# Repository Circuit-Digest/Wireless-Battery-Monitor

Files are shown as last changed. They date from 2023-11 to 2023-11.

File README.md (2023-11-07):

# Wireless-Battery-Monitor
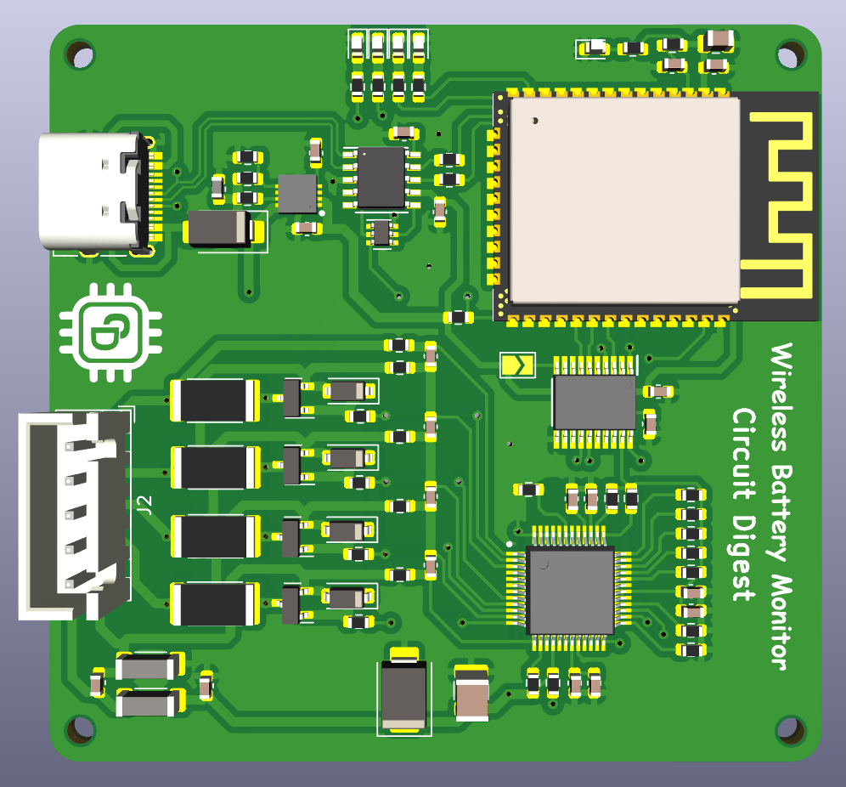
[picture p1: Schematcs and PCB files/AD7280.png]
image_tooltip

<br>

Batteries are everywhere and can be found in many of the day-to-day life equipment. Most of them are powered by Li ion or LIfepo4 batteries nowadays. Even though they need much less maintenance when compared to traditional Lead acid batteries, it is essential to regularly monitor them to avoid damage or even accidents. That’s where BMS comes into play. They not only provide safety but also help extend battery life. But the problem with most common BMSs is that, if we want to manually check the battery health, we will have to physically access it. There are BMS’s that offer wireless monitoring functionality, but the issue is that they are pretty expensive. That’s why we have decided to design and build a DIY wireless battery monitoring system, which can be used with the existing BMS.
For this project we have chosen the AD7280 Lithium-Ion Battery Monitoring chip from Analog Devices, and for wireless connectivity we have chosen our favourite ESP32. The AD7280 is capable of monitoring up to 6S battery configuration. Here we have configured it to monitor 4S battery configuration since that’s the most commonly used battery system. The AD7280 offers a 12bit ADC with a conversion time of 1 us per channel. It also features cell balancing function, which can be controlled manually. The ESP32 is used for communication and to host a Async webserver which can be used to monitor the cell voltages and charge levels.

<br>
[Note: As this projects are very simple we are only providing the code, schemaitic, and a few essential images if you want to get the images or code explanations do check out the Circuit Digest website.
<br>
<br>

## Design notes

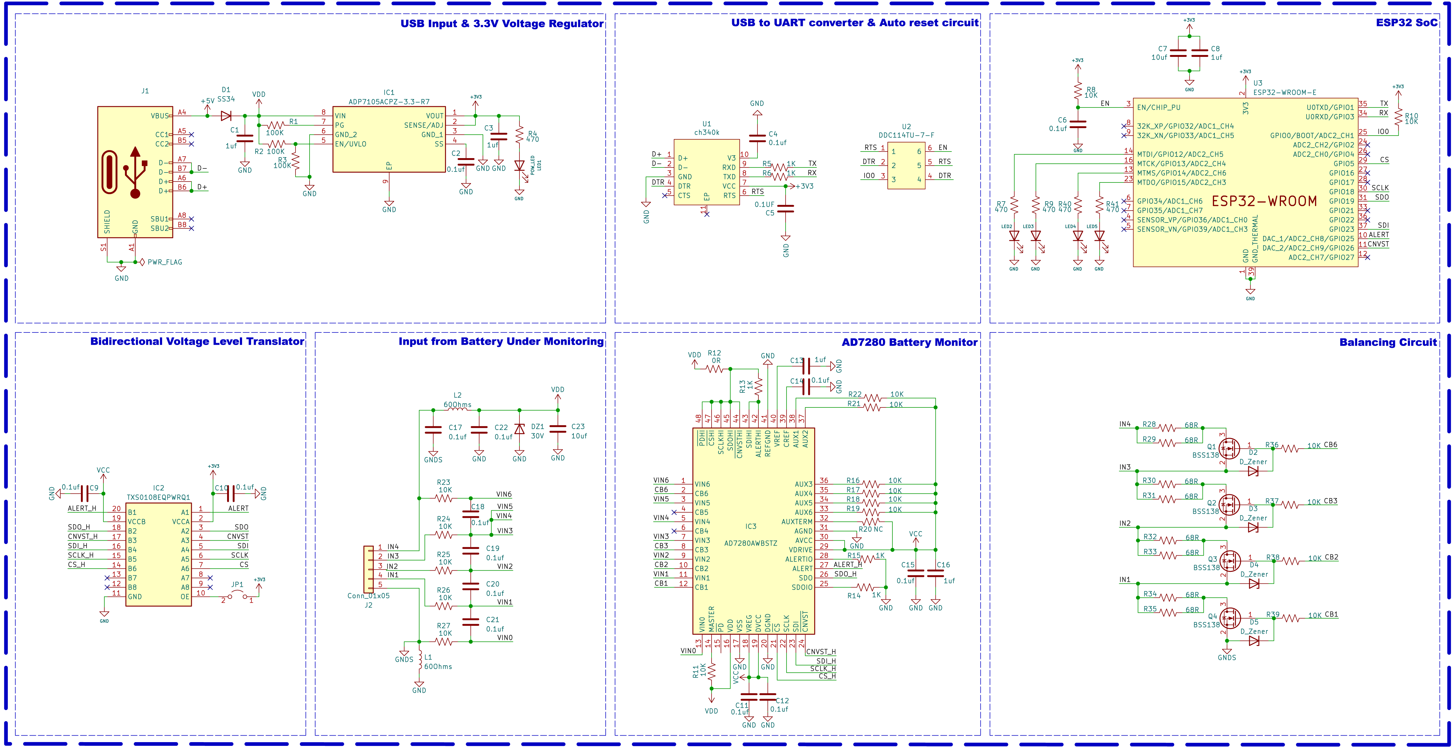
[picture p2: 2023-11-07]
Schematcs and PCB files/AD7280 sch.png

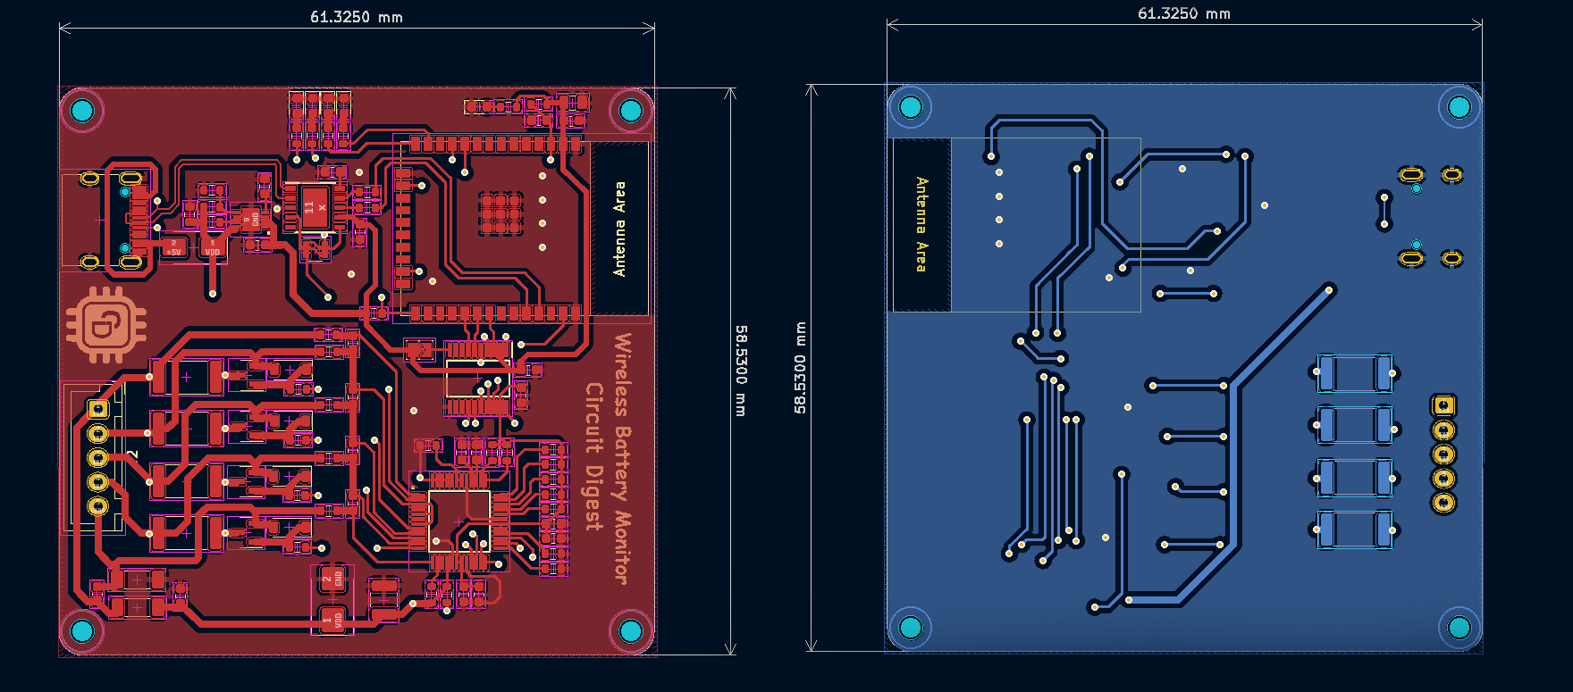
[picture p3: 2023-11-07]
Schematcs and PCB files/AD7280 PCB.png

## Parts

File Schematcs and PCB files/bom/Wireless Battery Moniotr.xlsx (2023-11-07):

Reference(s) | Value | Footprint | Manufacturer_Part_Number | Manufacturer_Name | Digikey Part Number | Digikey Link | Qty
C2, C4, C5, C6, C9, C10, C11, C12, C14, C15, C17, C18, C19, C20, C21, C22 | 0.1uf | C0603 | CL10B104KB8NNWC | Samsung Electro-Mechanics | 1276-1935-1-ND | https://www.digikey.in/en/products/detail/samsung-electro-mechanics/CL10B104KB8NNWC/3887593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 | 16
C1,C3, C8, C13, C16 | 1uf | C0603 | CL10A105KO8NNNC | Samsung Electro-Mechanics | 1276-1034-1-ND | https://www.digikey.in/en/products/detail/samsung-electro-mechanics/CL10A105KO8NNNC/3886692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 | 5
C7 | 10uf | C0805 | GRM21BR61H106KE43L | Murata Electronics | 490-18663-2-ND | https://www.digikey.in/en/products/detail/murata-electronics/GRM21BR61H106KE43L/10326316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 | 1
C23 | 10uf | C1210 | CL32B106KBJNNNE | Samsung Electro-Mechanics | 1276-3387-2-ND | https://www.digikey.in/en/products/detail/samsung-electro-mechanics/CL32B106KBJNNNE/3889045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 | 1
D1 | SS34 | SMA | SS34 | MDD | 3372-SS34TR-ND | https://www.digikey.in/en/products/detail/nextgen-components/SS34/15911595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 | 1
D2, D3, D4, D5 | D_Zener | SOD-123 | MMSZ15T1G | onsemi | MMSZ15T1GOSCT-ND | https://www.digikey.in/en/products/detail/onsemi/MMSZ15T1G/1749036 | 4
DZ1 | 30V | SMB | SMBJ30A-E3/5B | Vishay General Semiconductor | SMBJ30A-E3/5B-ND | https://www.digikey.in/en/products/detail/vishay-general-semiconductor-diodes-division/SMBJ30A-E3-5B/2147811 | 1
IC1 | ADP7105ACPZ-3.3-R7 | SON50 | ADP7105ACPZ-3.3-R7 | Analog Devices | 505-ADP7105ACPZ-3.3-R7CT-ND | https://www.digikey.in/en/products/detail/analog-devices-inc/ADP7105ACPZ-3-3-R7/10659634 | 2
IC2 | TXS0108EQPWRQ1 | SOP65 | TXS0108EQPWRQ1 | Texas Instruments | 296-42401-1-ND | https://www.digikey.in/en/products/detail/texas-instruments/TXS0108EQPWRQ1/5324256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 | 2
IC3 | AD7280AWBSTZ | QFP50 | AD7280AWBSTZ | Analog Devices | AD7280AWBSTZ-ND | https://www.digikey.in/en/products/detail/analog-devices-inc/AD7280AWBSTZ/2700188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 | 2
J1 | USB_C_Receptacle_USB2.0 | USB_C | USB4105-GF-A | GCT | 2073-USB4105-GF-ACT-ND | https://www.digikey.in/en/products/detail/gct/USB4105-GF-A/11198441 | 1
J2 | Conn_01x05 | JST_XH_B5B-XH-A_1x05 | B5B-XH-A(LF)(SN) | JST Sales America Inc. | 455-2270-ND | https://www.digikey.in/en/products/detail/jst-sales-america-inc/B5B-XH-A-LF-SN/1530483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 | 1
L1, L2 | 60Ohms | L1806 | BLM41PG600SN1L | Murata | 490-1058-2-ND | https://www.digikey.in/en/products/detail/murata-electronics/BLM41PG600SN1L/584267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 | 2
LED1 | RED LED | LED_0603 | 0603RBD0700S01 | BNDLIGHT | 3372-0603RBD0700S01TR-ND | https://www.digikey.in/en/products/detail/nextgen-components/0603RBD0700S01/14318421 | 1
LED2, LED3 | Blue LED | LED_0603 | 0603BBD0680S01 | BNDLIGHT | 3372-0603BBD0680S01TR-ND | https://www.digikey.in/en/products/detail/nextgen-components/0603BBD0680S01/14318406 | 4
Q1, Q2, Q3, Q4 | BSS138 | SOT-23 | BSS138-13-F | Diodes Incorporated | BSS138-13-F-ND | https://www.digikey.in/en/products/detail/diodes-incorporated/BSS138-13-F/9765697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 | 4
R1, R2, R3 | 100K | R0603 | CR0603JB100KS1 | Aillen | 3372-CR0603JB100KS1TR-ND | https://www.digikey.in/en/products/detail/nextgen-components/CR0603JB100KS1/14632365 | 3
R4, R7, R9 | 470R | R0603 | WR06X471 JTL | Walsin Technology Corporation | 1292-WR06X471JTLCT-ND | https://www.digikey.in/en/products/detail/walsin-technology-corporation/WR06X471-JTL/13240608 | 5
R5, R6, R13, R14, R15 | 1K | R0603 | RNCP0603FTD1K00 | Stackpole Electronics Inc | RNCP0603FTD1K00CT-ND | https://www.digikey.in/en/products/detail/stackpole-electronics-inc/RNCP0603FTD1K00/2240106 | 5
R8, R10, R11, R16, R17, R18, R19, R21, R22, R23, R24, R25, R26, R27, R36, R37, R38, R39 | 10K | R0603 | RNCP0603FTD10K0 | Stackpole Electronics Inc | RNCP0603FTD10K0CT-ND | https://www.digikey.in/en/products/detail/stackpole-electronics-inc/RNCP0603FTD10K0/2240139 | 18
R28, R29, R30, R31, R32, R33, R34, R35 | 68R | R2512 | RMCF2512JT68R0 | Stackpole Electronics Inc | 738-RMCF2512JT68R0CT-ND | https://www.digikey.in/en/products/detail/stackpole-electronics-inc/RMCF2512JT68R0/1756939 | 8
U1 | ch340k | ESSOP-10 |  |  |  |  | 1
U2 | DDC114TU-7-F | SOT-363 | DDC114TU-7-F | Diodes Incorporated | DDC114TU-FDICT-ND | https://www.digikey.in/en/products/detail/diodes-incorporated/DDC114TU-7-F/814919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 | 1
U3 | ESP32-WROOM-E | ESP32-WROOM-32E | ESP32-WROOM-32E-N16 | Espressif Systems | 1965-ESP32-WROOM-32E-N16CT-ND | https://www.digikey.in/en/products/detail/espressif-systems/ESP32-WROOM-32E-N16/11613144 | 1
U4 | ADUM3165 | ADUM3165BRSZ | ADUM3165BRSZ | Analog Devices Inc. | 505-ADUM3165BRSZ-ND | https://www.digikey.in/en/products/detail/analog-devices-inc/ADUM3165BRSZ/16580732 | 2

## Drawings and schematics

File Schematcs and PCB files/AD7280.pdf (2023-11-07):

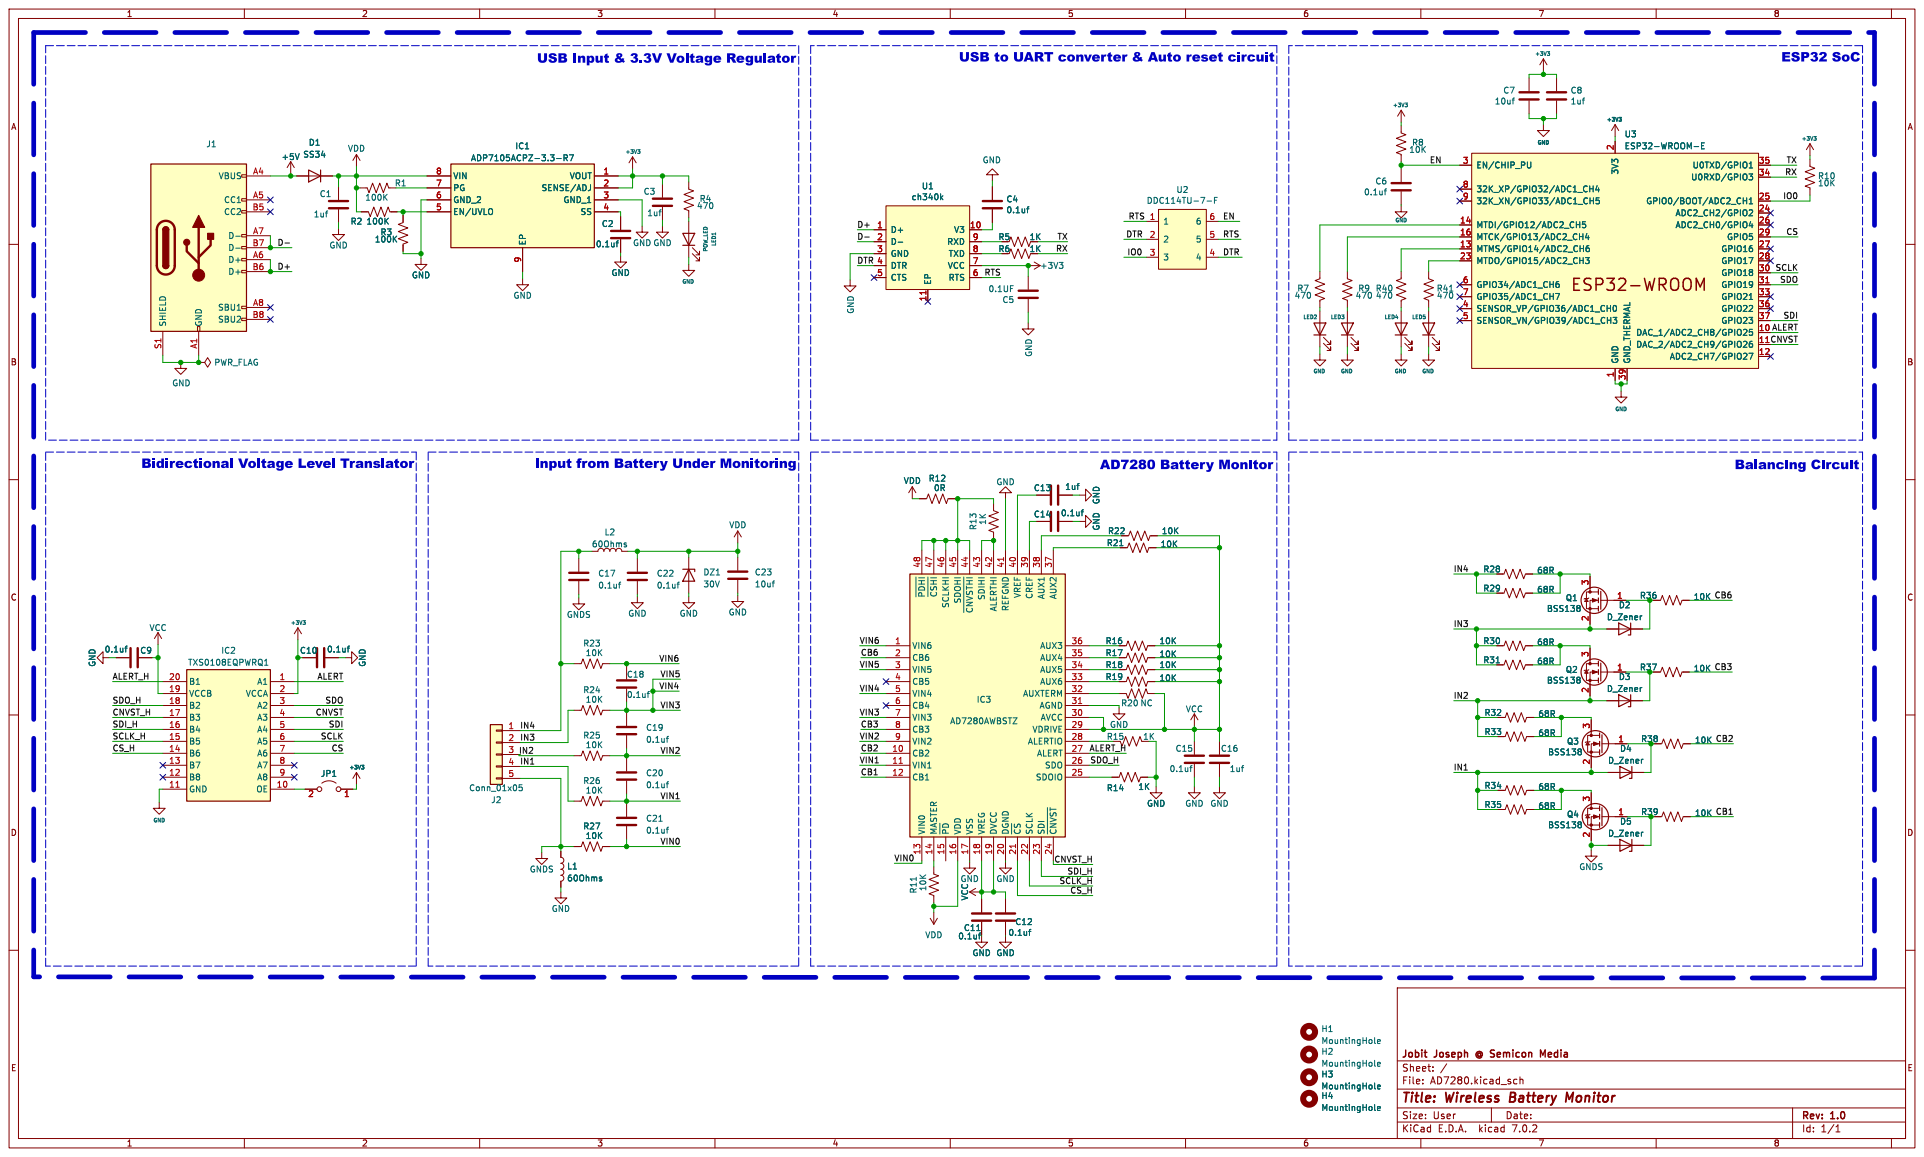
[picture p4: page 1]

USB Input & 3.3V Voltage Regulator

USB to UART converter & Auto reset circuit

Bidirectional Voltage Level Translator

H4 MountingHole H2 MountingHole H3 MountingHole H1 MountingHole

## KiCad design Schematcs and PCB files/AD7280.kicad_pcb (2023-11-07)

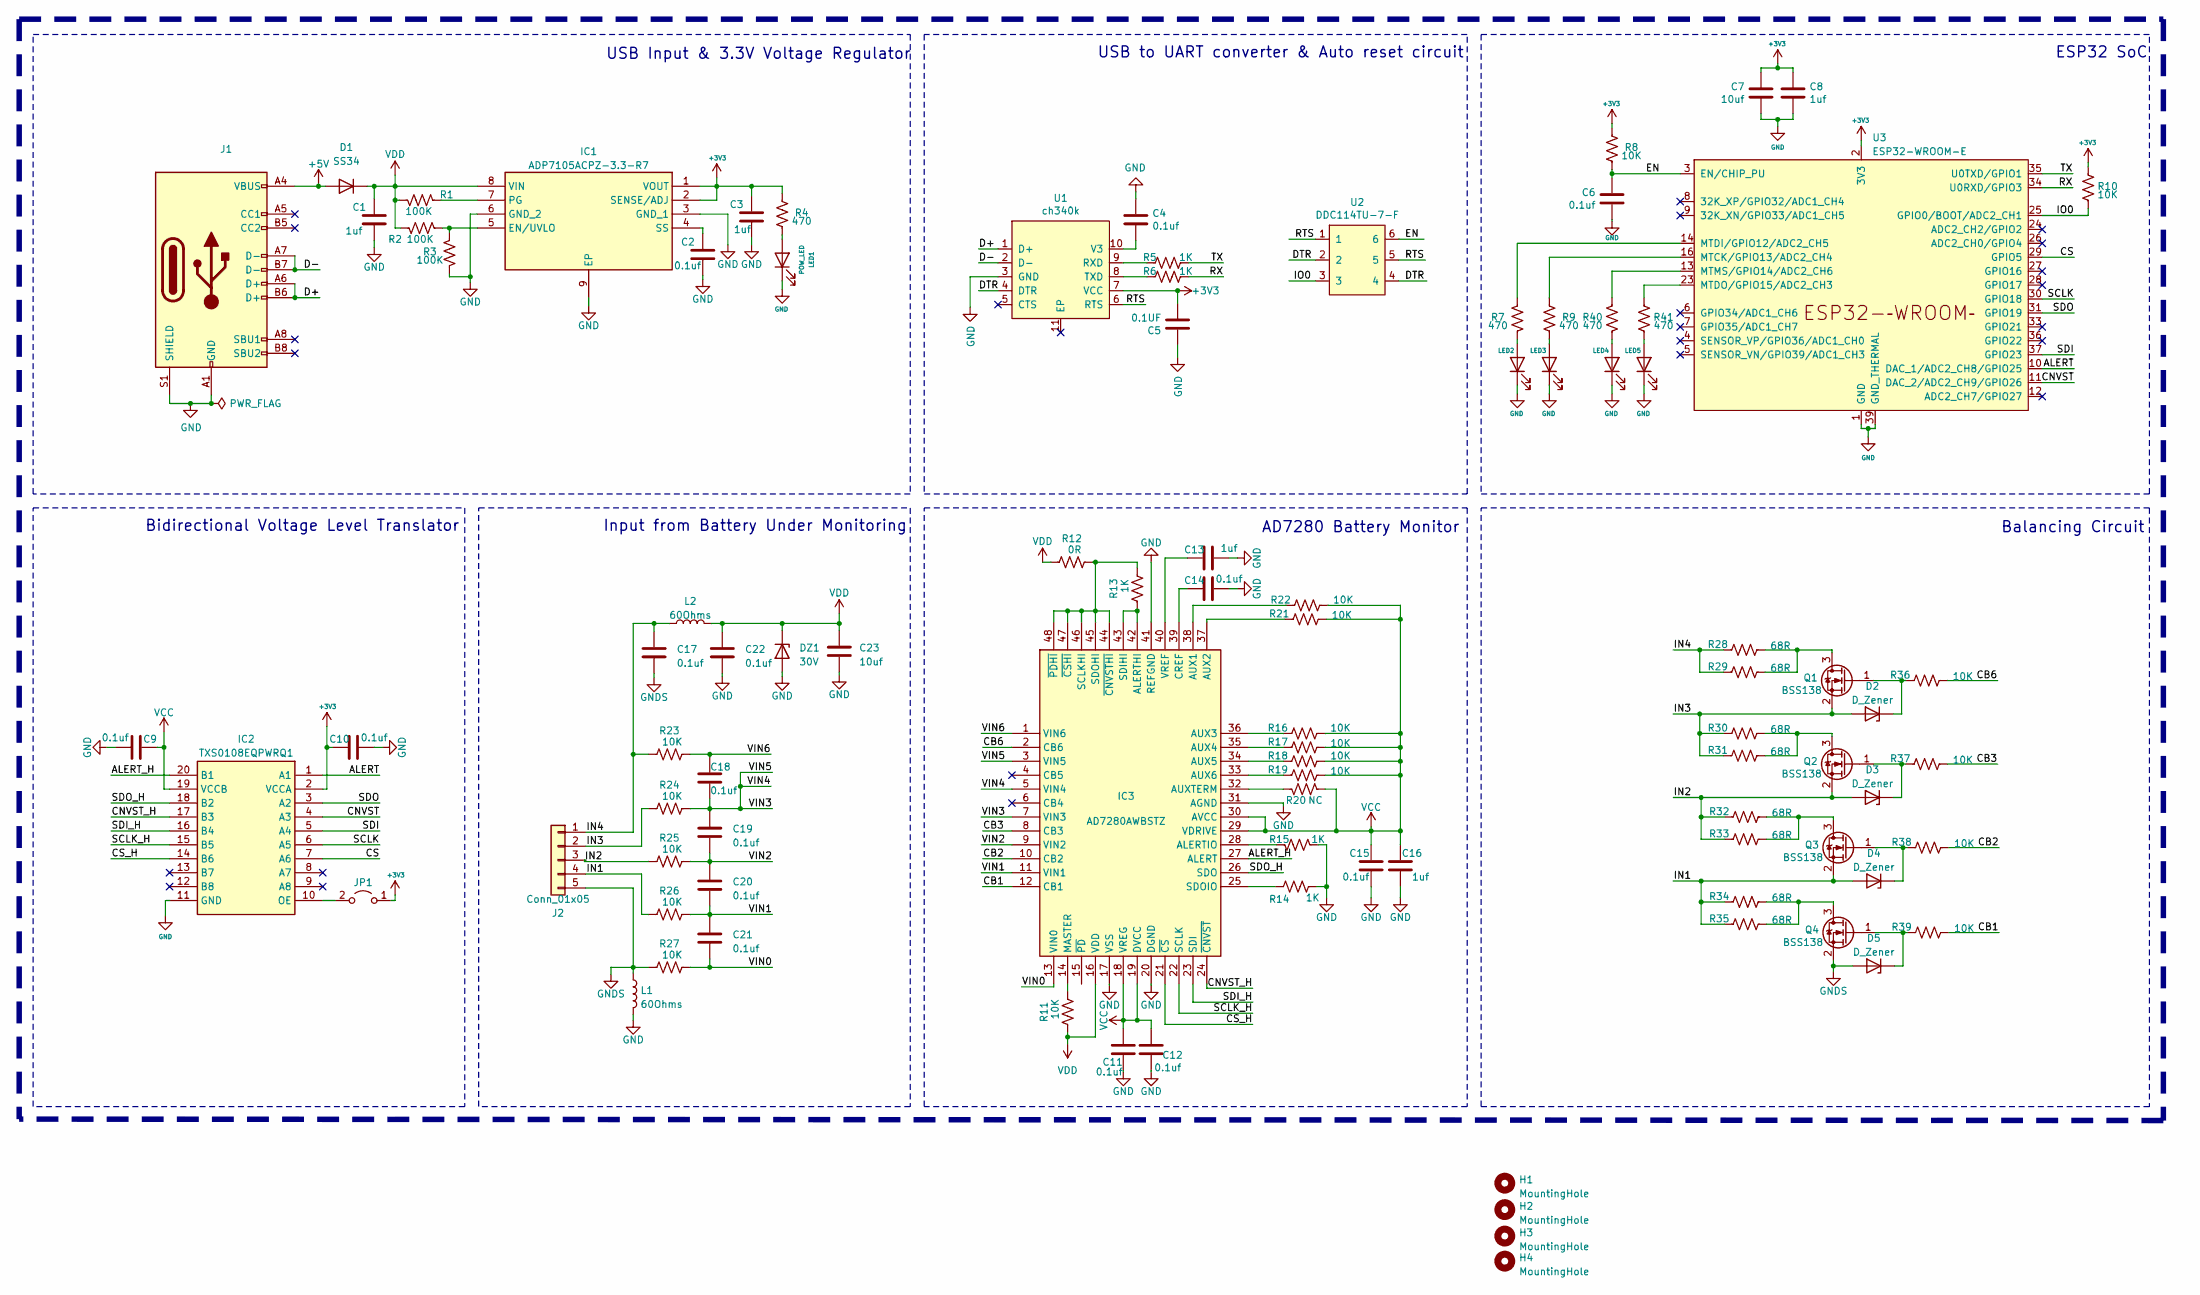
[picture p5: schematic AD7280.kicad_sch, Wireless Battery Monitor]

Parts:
C1: 1uf; L_0603_1608Metric
C2, C4, C6, C9, C10, C11, C12, C14, C15, C17, C18, C19, C20, C21, C22: 0.1uf; C_0603_1608Metric
C3, C8, C13, C16: 1uf; C_0603_1608Metric
C5: 0.1UF; C_0603_1608Metric
C7: 10uf; C_0805_2012Metric
C23: 10uf; C_1210_3225Metric
D1: SS34; D_SMA
D2, D3, D4, D5: D_Zener; D_SOD-123
DZ1: 30V; D_SMB
H1, H2, H3, H4: MountingHole; MountingHole_2.1mm
IC1: ADP7105ACPZ-3.3-R7; SON50P300X300X80-9N-D; Mouser Part Number 584-P7105ACPZ-3.3-R
IC2: TXS0108EQPWRQ1; SOP65P640X120-20N; Mouser Part Number 595-TXS0108EQPWRQ1
IC3: AD7280AWBSTZ; QFP50P900X900X160-48N; Mouser Part Number 584-AD7280AWBSTZ
J1: USB_C_Receptacle_USB2.0; USB_C_Receptacle_HRO_TYPE-C-31-M-12
J2: Conn_01x05; JST_XH_B5B-XH-A_1x05_P2.50mm_Vertical
JP1: Jumper_2_Open; SolderJumper-2_P1.3mm_Open_TrianglePad1.0x1.5mm
L1, L2: 60Ohms; L_1806_4516Metric; MFG Part number BLM41PG600SN1L
LED1, LED2, LED3, LED4, LED5: POW_LED; LED_0603_1608Metric
Q1, Q2, Q3, Q4: BSS138; SOT-23
R1, R2, R3: 100K; R_0603_1608Metric
R4, R7, R9, R40, R41: 470; R_0603_1608Metric
R5, R6, R13, R14, R15: 1K; R_0603_1608Metric
R8, R10, R11, R16, R17, R18, R19, R21, R22, R23, R24, R25, R26, R27, R36, R37, R38, R39: 10K; R_0603_1608Metric
R12: 0R; R_0603_1608Metric
R20: NC; R_0603_1608Metric
R28, R29, R30, R31, R32, R33, R34, R35: 68R; R_2512_6332Metric
U1: ch340k; ESSOP-10_3.9x4.9mm_P1.00mm
U2: DDC114TU-7-F; SOT-363_SC-70-6
U3: ESP32-WROOM-E; ESP32-WROOM-32E

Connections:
+3V3: C3.1, C5.2, C7.1, C8.1, C10.1, IC1.1 (VOUT), IC1.2 (SENSE/ADJ), IC2.2 (VCCA), JP1.1 (A), R4.2, R8.2, R10.2, U1.7 (VCC), U3.2 (3V3)
+5V: D1.2 (A), J1.A4 (VBUS), J1.A9 (VBUS), J1.B4 (VBUS), J1.B9 (VBUS)
/ALERT: IC2.1 (A1), U3.10 (DAC_1/ADC2_CH8/GPIO25)
/ALERT_H: IC2.20 (B1), IC3.27 (ALERT)
/CB1: IC3.12 (CB1), R39.2
/CB2: IC3.10 (CB2), R38.2
/CB3: IC3.8 (CB3), R37.2
/CB6: IC3.2 (CB6), R36.2
/CNVST: IC2.4 (A3), U3.11 (DAC_2/ADC2_CH9/GPIO26)
/CNVST_H: IC2.17 (B3), IC3.24 (~CNVST)
/CS: IC2.7 (A6), U3.29 (GPIO5)
/CS_H: IC2.14 (B6), IC3.21 (~CS)
/D+: J1.A6 (D+), J1.B6 (D+), U1.1 (D+)
/D-: J1.A7 (D-), J1.B7 (D-), U1.2 (D-)
/DTR: U1.4 (DTR), U2.2, U2.4
/EN: C6.1, R8.1, U2.6, U3.3 (EN/CHIP_PU)
/IN1: D4.2 (A), J2.4, Q3.2 (S), R26.1, R34.1, R35.1
/IN2: D3.2 (A), J2.3, Q2.2 (S), R25.1, R32.1, R33.1
/IN3: D2.2 (A), J2.2, Q1.2 (S), R24.1, R30.1, R31.1
/IN4: C17.1, J2.1, L2.1, R23.1, R28.1, R29.1
/IO0: R10.1, U2.3, U3.25 (GPIO0/BOOT/ADC2_CH1)
/RTS: U1.6 (RTS), U2.1, U2.5
/RX: R6.2, U3.34 (U0RXD/GPIO3)
/SCLK: IC2.6 (A5), U3.30 (GPIO18)
/SCLK_H: IC2.15 (B5), IC3.22 (SCLK)
/SDI: IC2.5 (A4), U3.37 (GPIO23)
/SDI_H: IC2.16 (B4), IC3.23 (SDI)
/SDO: IC2.3 (A2), U3.31 (GPIO19)
/SDO_H: IC2.18 (B2), IC3.26 (SDO)
/TX: R5.2, U3.35 (U0TXD/GPIO1)
/VIN0: C21.2, IC3.13 (VIN0), R27.2
/VIN1: C20.2, C21.1, IC3.11 (VIN1), R26.2
/VIN2: C19.2, C20.1, IC3.9 (VIN2), R25.2
/VIN3: C18.2, C19.1, IC3.3 (VIN5), IC3.5 (VIN4), IC3.7 (VIN3), R24.2
/VIN6: C18.1, IC3.1 (VIN6), R23.2
GND: C1.2, C2.2, C3.2, C4.1, C5.1, C6.2, C7.2, C8.2, C9.2, C10.2, C11.2, C12.2, C13.2, C14.2, C15.2, C16.2, C22.2, C23.2, DZ1.2 (A), IC1.3 (GND_1), IC1.6 (GND_2), IC1.9 (EP), IC2.11 (GND), IC3.17 (VSS), IC3.20 (DGND), IC3.31 (AGND), IC3.41 (REFGND), J1.A1 (GND), J1.A12 (GND), J1.B1 (GND), J1.B12 (GND), J1.S1 (SHIELD), L1.2, LED1.1 (K), LED2.1 (K), LED3.1 (K), LED4.1 (K), LED5.1 (K), R3.1, R14.1, R15.2, U1.3 (GND), U3.1 (GND), U3.15 (GND), U3.38 (GND), U3.39 (GND_THERMAL)
GNDS: C17.2, D5.2 (A), J2.5, L1.1, Q4.2 (S), R27.1
unnamed: D2.1 (K), Q1.1 (G), R36.1
unnamed: D3.1 (K), Q2.1 (G), R37.1
unnamed: D4.1 (K), Q3.1 (G), R38.1
unnamed: D5.1 (K), Q4.1 (G), R39.1
unnamed: IC1.5 (EN/UVLO), R2.1, R3.2
unnamed: IC1.7 (PG), R1.1
unnamed: C2.1, IC1.4 (SS)
unnamed: IC2.10 (OE), JP1.2 (B)
unnamed: IC3.42 (ALERTHI), IC3.43 (SDIHI), R13.1
unnamed: IC3.28 (ALERTIO), R15.1
unnamed: IC3.38 (AUX1), R22.1
unnamed: IC3.37 (AUX2), R21.1
unnamed: IC3.36 (AUX3), R16.1
unnamed: IC3.35 (AUX4), R17.1
unnamed: IC3.34 (AUX5), R18.1
unnamed: IC3.33 (AUX6), R19.1
unnamed: IC3.32 (AUXTERM), R20.1
unnamed: C14.1, IC3.39 (CREF)
unnamed: IC3.14 (MASTER), R11.2
unnamed: IC3.44 (~CNVSTHI), IC3.45 (SDOHI), IC3.46 (SCLKHI), IC3.47 (~CSHI), IC3.48 (~PDHI), R12.2, R13.2
unnamed: IC3.25 (SDOIO), R14.2
unnamed: C13.1, IC3.40 (VREF)
unnamed: LED1.2 (A), R4.1
unnamed: LED2.2 (A), R7.1
unnamed: LED3.2 (A), R9.1
unnamed: LED4.2 (A), R40.1
unnamed: LED5.2 (A), R41.1
unnamed: Q1.3 (D), R28.2, R29.2
unnamed: Q2.3 (D), R30.2, R31.2
unnamed: Q3.3 (D), R32.2, R33.2
unnamed: Q4.3 (D), R34.2, R35.2
unnamed: R5.1, U1.9 (RXD)
unnamed: R6.1, U1.8 (TXD)
unnamed: C4.2, U1.10 (V3)
unnamed: R9.2, U3.16 (MTCK/GPIO13/ADC2_CH4)
unnamed: R7.2, U3.14 (MTDI/GPIO12/ADC2_CH5)
unnamed: R41.2, U3.23 (MTDO/GPIO15/ADC2_CH3)
unnamed: R40.2, U3.13 (MTMS/GPIO14/ADC2_CH6)
VCC: C9.1, C11.1, C12.1, C15.1, C16.1, IC2.19 (VCCB), IC3.18 (VREG), IC3.19 (DVCC), IC3.29 (VDRIVE), IC3.30 (AVCC), R16.2, R17.2, R18.2, R19.2, R20.2, R21.2, R22.2
VDD: C1.1, C22.1, C23.1, D1.1 (K), DZ1.1 (K), IC1.8 (VIN), IC3.16 (VDD), L2.2, R1.2, R2.2, R11.1, R12.1

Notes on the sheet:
Balancing Circuit
Input from Battery Under Monitoring
ESP32 SoC
Bidirectional Voltage Level Translator
USB to UART converter & Auto reset circuit
USB Input & 3.3V Voltage Regulator
AD7280 Battery Monitor

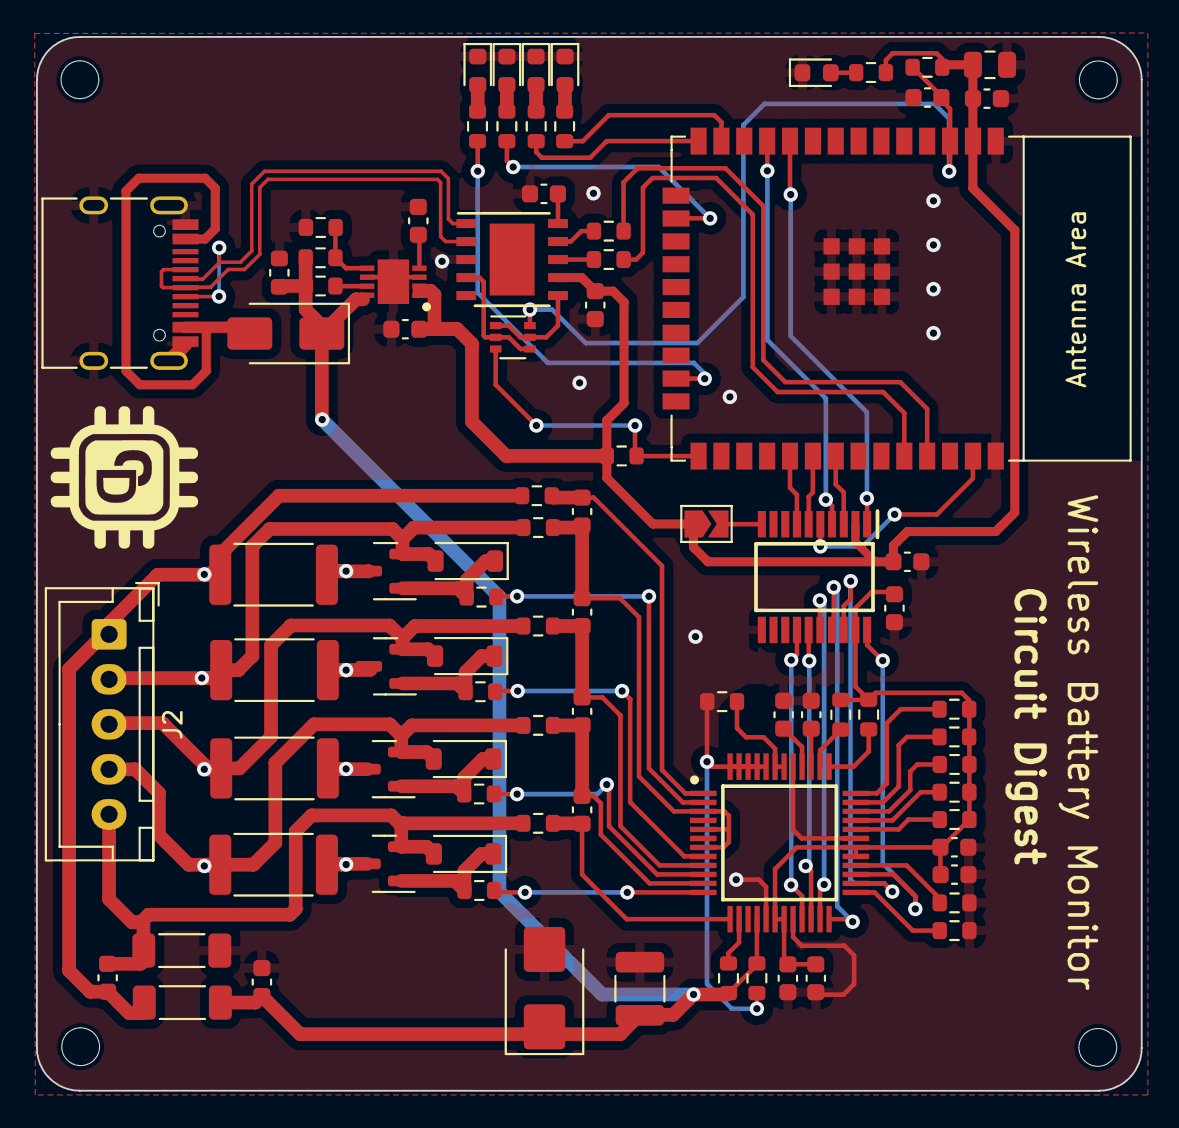
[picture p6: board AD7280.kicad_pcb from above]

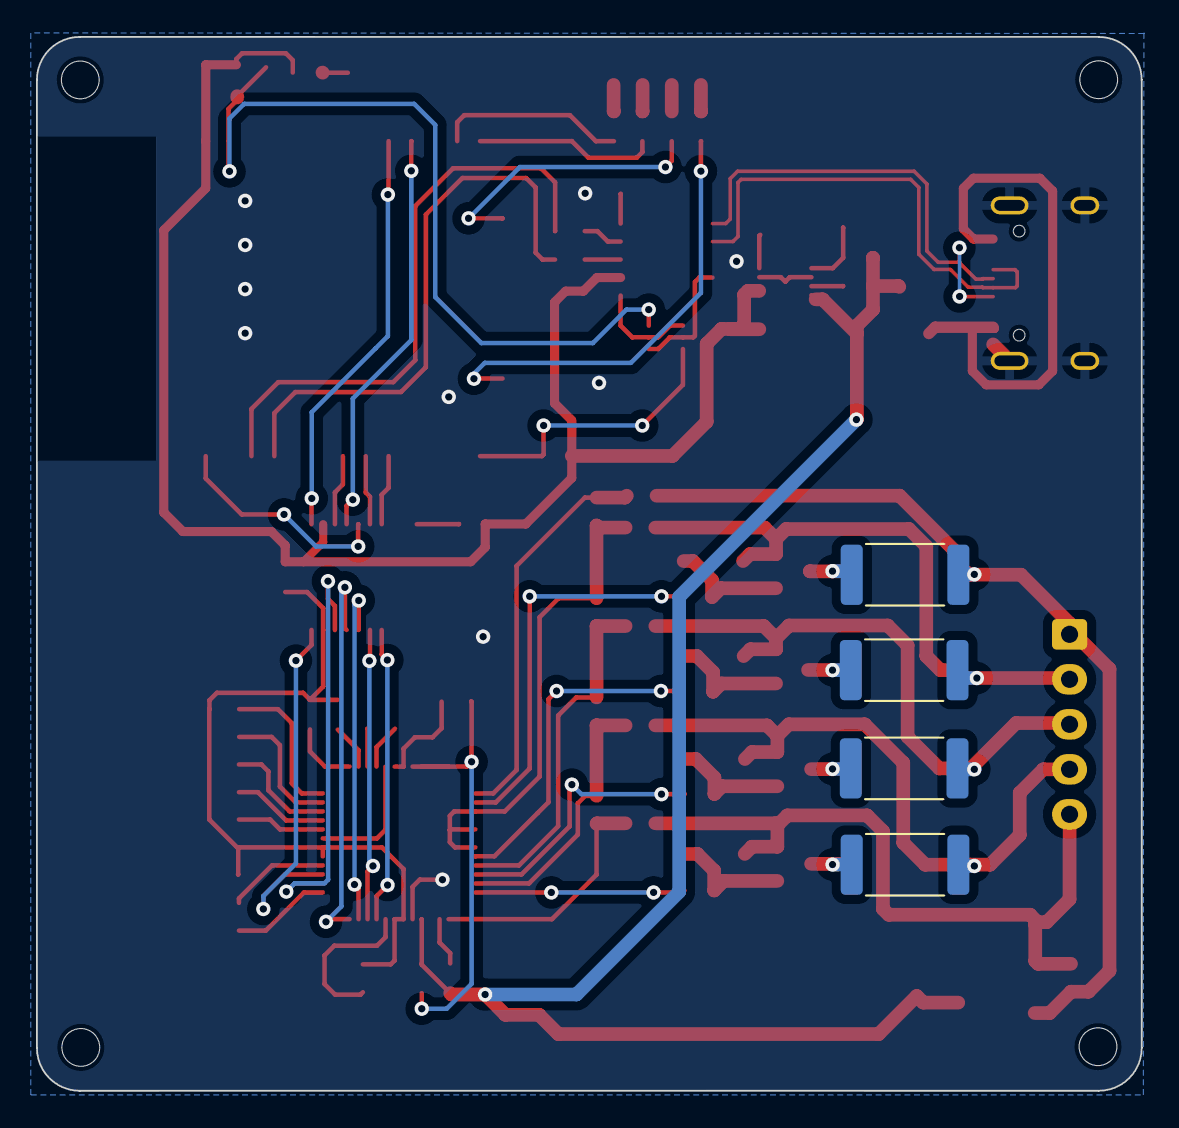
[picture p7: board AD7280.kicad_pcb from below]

Board: 2 copper layers, 61.4 x 58.6 mm, 94 parts (4 on the bottom side), 77 nets.

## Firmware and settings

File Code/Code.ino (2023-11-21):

/*
 * Project Name: Wireless Battery Monitor
 * Project Brief: Firmware for Wireless Battery Monitor built around ESP32 and AD7280
 * Author: Jobit Joseph
 * Copyright © Jobit Joseph
 * Copyright © Semicon Media Pvt Ltd
 * Copyright © Circuitdigest.com
 * 
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
 */
#include <Arduino.h>
#include <SPI.h>
#include <WiFi.h>
#include <ESPAsyncWebServer.h>

/* AD7280 CS pin Definition */
#ifndef _SS
#define _SS 5
#endif
/* AD7280 CS pin Definition */

/* AD7280 Register mapping */
#define _PDEBUG
#define AD7280A_ACQ_TIME_400ns 0
#define AD7280A_ACQ_TIME_800ns 1
#define AD7280A_ACQ_TIME_1200ns 2
#define AD7280A_ACQ_TIME_1600ns 3
#define AD7280A_CONV_AVG_DIS 0
#define AD7280A_CONV_AVG_2 1
#define AD7280A_CONV_AVG_4 2
#define AD7280A_CONV_AVG_8 3
#define AD7280A_ALERT_REMOVE_VIN5 (1 << 2)
#define AD7280A_ALERT_REMOVE_VIN4_VIN5 (2 << 2)
#define AD7280A_ALERT_REMOVE_AUX5 (1 << 0)
#define AD7280A_ALERT_REMOVE_AUX4_AUX5 (2 << 0)
#define AD7280A_CELL_VOLTAGE_1 0x0        /* D11 to D0, Read only */
#define AD7280A_CELL_VOLTAGE_2 0x1        /* D11 to D0, Read only */
#define AD7280A_CELL_VOLTAGE_3 0x2        /* D11 to D0, Read only */
#define AD7280A_CELL_VOLTAGE_4 0x3        /* D11 to D0, Read only */
#define AD7280A_CELL_VOLTAGE_5 0x4        /* D11 to D0, Read only */
#define AD7280A_CELL_VOLTAGE_6 0x5        /* D11 to D0, Read only */
#define AD7280A_AUX_ADC_1 0x6             /* D11 to D0, Read only */
#define AD7280A_AUX_ADC_2 0x7             /* D11 to D0, Read only */
#define AD7280A_AUX_ADC_3 0x8             /* D11 to D0, Read only */
#define AD7280A_AUX_ADC_4 0x9             /* D11 to D0, Read only */
#define AD7280A_AUX_ADC_5 0xA             /* D11 to D0, Read only */
#define AD7280A_AUX_ADC_6 0xB             /* D11 to D0, Read only */
#define AD7280A_SELF_TEST 0xC             /* D11 to D0, Read only */
#define AD7280A_CONTROL_HB 0xD            /* D15 to D8, Read/write */
#define AD7280A_CONTROL_LB 0xE            /* D7 to D0, Read/write */
#define AD7280A_CELL_OVERVOLTAGE 0xF      /* D7 to D0, Read/write */
#define AD7280A_CELL_UNDERVOLTAGE 0x10    /* D7 to D0, Read/write */
#define AD7280A_AUX_ADC_OVERVOLTAGE 0x11  /* D7 to D0, Read/write */
#define AD7280A_AUX_ADC_UNDERVOLTAGE 0x12 /* D7 to D0, Read/write */
#define AD7280A_ALERT 0x13                /* D7 to D0, Read/write */
#define AD7280A_CELL_BALANCE 0x14         /* D7 to D0, Read/write */
#define AD7280A_CB1_TIMER 0x15            /* D7 to D0, Read/write */
#define AD7280A_CB2_TIMER 0x16            /* D7 to D0, Read/write */
#define AD7280A_CB3_TIMER 0x17            /* D7 to D0, Read/write */
#define AD7280A_CB4_TIMER 0x18            /* D7 to D0, Read/write */
#define AD7280A_CB5_TIMER 0x19            /* D7 to D0, Read/write */
#define AD7280A_CB6_TIMER 0x1A            /* D7 to D0, Read/write */
#define AD7280A_PD_TIMER 0x1B             /* D7 to D0, Read/write */
#define AD7280A_READ 0x1C                 /* D7 to D0, Read/write */
#define AD7280A_CNVST_CONTROL 0x1D        /* D7 to D0, Read/write */
/* Bits and Masks */
#define AD7280A_CTRL_HB_CONV_INPUT_ALL (0 << 6)
#define AD7280A_CTRL_HB_CONV_INPUT_6CELL_AUX1_3_4 (1 << 6)
#define AD7280A_CTRL_HB_CONV_INPUT_6CELL (2 << 6)
#define AD7280A_CTRL_HB_CONV_INPUT_SELF_TEST (3 << 6)
#define AD7280A_CTRL_HB_CONV_RES_READ_ALL (0 << 4)
#define AD7280A_CTRL_HB_CONV_RES_READ_6CELL_AUX1_3_4 (1 << 4)
#define AD7280A_CTRL_HB_CONV_RES_READ_6CELL (2 << 4)
#define AD7280A_CTRL_HB_CONV_RES_READ_NO (3 << 4)
#define AD7280A_CTRL_HB_CONV_START_CNVST (0 << 3)
#define AD7280A_CTRL_HB_CONV_START_CS (1 << 3)
#define AD7280A_CTRL_HB_CONV_AVG_DIS (0 << 1)
#define AD7280A_CTRL_HB_CONV_AVG_2 (1 << 1)
#define AD7280A_CTRL_HB_CONV_AVG_4 (2 << 1)
#define AD7280A_CTRL_HB_CONV_AVG_8 (3 << 1)
#define AD7280A_CTRL_HB_CONV_AVG(x) ((x) << 1)
#define AD7280A_CTRL_HB_PWRDN_SW (1 << 0)
#define AD7280A_CTRL_LB_SWRST (1 << 7)
#define AD7280A_CTRL_LB_ACQ_TIME_400ns (0 << 5)
#define AD7280A_CTRL_LB_ACQ_TIME_800ns (1 << 5)
#define AD7280A_CTRL_LB_ACQ_TIME_1200ns (2 << 5)
#define AD7280A_CTRL_LB_ACQ_TIME_1600ns (3 << 5)
#define AD7280A_CTRL_LB_ACQ_TIME(x) ((x) << 5)
#define AD7280A_CTRL_LB_MUST_SET (1 << 4)
#define AD7280A_CTRL_LB_THERMISTOR_EN (1 << 3)
#define AD7280A_CTRL_LB_LOCK_DEV_ADDR (1 << 2)
#define AD7280A_CTRL_LB_INC_DEV_ADDR (1 << 1)
#define AD7280A_CTRL_LB_DAISY_CHAIN_RB_EN (1 << 0)
#define AD7280A_ALERT_GEN_STATIC_HIGH (1 << 6)
#define AD7280A_ALERT_RELAY_SIG_CHAIN_DOWN (3 << 6)
#define AD7280A_ALL_CELLS (0x00AD << 16)
#define AD7280A_MAX_SPI_CLK_Hz 700000 /* < 1MHz */
#define AD7280A_MAX_CHAIN 8
#define AD7280A_CELLS_PER_DEV 6
#define AD7280A_BITS 12
#define AD7280A_NUM_CH (AD7280A_AUX_ADC_6 - AD7280A_CELL_VOLTAGE_1 + 1)
#define AD7280A_DEVADDR_MASTER 0
#define AD7280A_DEVADDR_ALL 0x1F
/* 5-bit device address is sent LSB first */
#define AD7280A_DEVADDR(addr) (((addr & 0x1) << 4) | ((addr & 0x2) << 3) | (addr & 0x4) | ((addr & 0x8) >> 3) | ((addr & 0x10) >> 4))
#define AD7280A_READ_TXVAL 0xF800030A
#define POLYNOM 0x2F
#define POLYNOM_ORDER 8
#define HIGHBIT 1 << (POLYNOM_ORDER - 1);
/* AD7280 Register mapping */

/* AD7280 data structure */
struct ad7280_state {
  int16_t slave_num;
  int16_t scan_cnt;
  uint8_t readback_delay_ms;
  uint8_t crc_tab[256];
  uint8_t ctrl_hb;
  uint8_t ctrl_lb;
  uint8_t cell_threshhigh;
  uint8_t cell_threshlow;
  uint8_t aux_threshhigh;
  uint8_t aux_threshlow;
  uint8_t cb_mask[AD7280A_MAX_CHAIN];
  struct spi_device *spi;
};
/* AD7280 data structure */

struct spi_device {
  int8_t spi;
};

//Global Variables
int LEDPins[] = {15, 13, 12, 14};
unsigned long previousMillis = 0;
unsigned long lastMillis = 0;
unsigned long interval = 30000;
struct ad7280_state ADinst;
uint16_t valCh[12];  

//WiFi Credentials
const char *ssid = "CircuitDigest";
const char *password = "circuitdigest123";

//Async Webserver instance
AsyncWebServer server(80);
AsyncWebSocket ws("/ws");

/*Wireless battery monitor Web page*/
const char *htmlPage = R"rawliteral(
<!DOCTYPE html>
<html lang="en">
<head>
  <meta charset="UTF-8">
  <meta http-equiv="X-UA-Compatible" content="IE=edge">
  <meta name="viewport" content="width=device-width, initial-scale=1.0">
  <title>Wireless Battery Monito</title>
  <script src="https://cdn.jsdelivr.net/npm/reconnecting-websocket@4.4.0/dist/reconnecting-websocket.min.js"></script>
  <style>
    body {
      display: flex;
      justify-content: center;
      align-items: center;
      height: 50vh;
      margin: 0;
      font-family: Arial, sans-serif;
      flex-wrap: wrap;
    }
    h1 {
      text-align: center;
      width: 100%;
      font-size: 24px;
      margin-top: 20px;
    }
    .total-voltage-container {
      width: 100%;
      text-align: center;
      font-size: 20px;
      font-weight: bold;
      margin: 10px 0;
    }
    .battery-container {
      display: flex;
      flex-direction: column;
      align-items: center;
      margin: 20px;
    }
    .battery {
      width: 100px;
      height: 200px;
      position: relative;
      border: 3px solid black;
    }
    .battery:after {
      content: "";
      position: absolute;
      top: -15px;
      left: 35px;
      width: 30px;
      height: 10px;
      background: black;
    }
    .battery-level {
      width: 100%;
      position: absolute;
      bottom: 0;
      background: green;
      text-align: center;
      color: white;
      font-weight: bold;
    }
    .voltage {
      font-size: 18px;
      margin-top: 10px;
    }
  </style>
</head>
<body>
  <h1>Wireless Battery Monitor</h1>
  <div class="total-voltage-container">
    <div id="totalVoltage" class="voltage">Total Voltage: 0mV</div>
    <div id="totalPercentage" class="voltage">Total Percentage: 0%</div>
  </div>
  <div class="battery-container">
    <div id="battery1" class="battery"><div class="battery-level" style="height: 0%;">0%</div></div>
    <div id="voltage1" class="voltage">0mV</div>
  </div>
  <div class="battery-container">
    <div id="battery2" class="battery"><div class="battery-level" style="height: 0%;">0%</div></div>
    <div id="voltage2" class="voltage">0mV</div>
  </div>
  <div class="battery-container">
    <div id="battery3" class="battery"><div class="battery-level" style="height: 0%;">0%</div></div>
    <div id="voltage3" class="voltage">0mV</div>
  </div>
  <div class="battery-container">
    <div id="battery4" class="battery"><div class="battery-level" style="height: 0%;">0%</div></div>
    <div id="voltage4" class="voltage">0mV</div>
  </div>
  
<script>
  var ws = new WebSocket('ws://' + location.hostname + '/ws');
  ws.onopen = function() {
    console.log("WebSocket connection opened");
  };
  ws.onclose = function() {
    console.log("WebSocket connection closed");
    setTimeout(function() {
      ws = new WebSocket('ws://' + location.hostname + '/ws');
    }, 5000);
  };
  ws.onmessage = function(event) {
    console.log("Data received:", event.data);
    var data = JSON.parse(event.data);
    for (var i = 1; i <= 4; i++) {
      var battery = document.getElementById('battery' + i);
      var level = battery.querySelector('.battery-level');
      var voltage = document.getElementById('voltage' + i);
      level.style.height = data.percentages[i - 1] + '%';
      level.textContent = data.percentages[i - 1] + '%';
      voltage.textContent = data.voltages[i - 1] + 'mV';
    }
    document.getElementById('totalVoltage').textContent = "Total Voltage: " + data.totalVoltage + "mV";
    document.getElementById('totalPercentage').textContent = "Total Percentage: " + data.totalPercentage + "%";
  };
</script>
</body>
</html>
)rawliteral";
/*Wireless battery monitor Web page*/

/*Websocket event handler*/
void onWebSocketEvent(AsyncWebSocket *server, AsyncWebSocketClient *client,
                      AwsEventType type, void *arg, uint8_t *data, size_t len) {
  if (type == WS_EVT_CONNECT) {
    Serial.println("Websocket client connection received");
  } else if (type == WS_EVT_DISCONNECT) {
    Serial.println("Client disconnected");
  } else if (type == WS_EVT_DATA) {
    AwsFrameInfo *info = (AwsFrameInfo *)arg;
    String msg = "";
    if (info->final && info->index == 0 && info->len == len) {
      for (size_t i = 0; i < info->len; i++) {
        msg += (char)data[i];
      }
      Serial.println(msg);
    }
  }
}

/* SPI Setup function */
void setup_spi32() {
  SPI.begin();
  /*
  SPI.setDataMode(SPI_MODE1);
  SPI.setBitOrder(MSBFIRST);             // MSB first.
  SPI.setClockDivider(SPI_CLOCK_DIV16);  // 1 Mhz Clk fo SPI. 16Mhz Div 16 = 1 Mhz.s
  */
  SPISettings mySPISettings(500000, MSBFIRST, SPI_MODE1); // 500 kHz speed, MSB first, Mode 1
  // Begin SPI transaction with the defined settings
  SPI.beginTransaction(mySPISettings);
  pinMode(_SS, OUTPUT);
}

/* 32bit to 4x 8bit conversion*/
void transferspi32(uint32_t *val) {
  byte h_h;  // D31-D24 received
  byte h_l;  // D23-D16 received
  byte l_h;  // D15 -D8 received
  byte l_l;  // D07 -D0 received

#ifndef _PDEBUG
  h_h = ((*val) >> 24) & 0xFF;
  h_l = ((*val) >> 16) & 0xFF;
  l_h = ((*val) >> 8) & 0xFF;
  l_l = (*val) & 0xFF;
  Serial.println("=================");
  Serial.println("Sending SPI32bit");
  Serial.print("HEX: ");
  Serial.print(h_h, HEX);
  Serial.print(",");
  Serial.print(h_l, HEX);
  Serial.print(",");
  Serial.print(l_h, HEX);
  Serial.print(",");
  Serial.println(l_l, HEX);
  Serial.print("BIN: ");
  Serial.print(h_h, BIN);
  Serial.print(",");
  Serial.print(h_l, BIN);
  Serial.print(",");
  Serial.print(l_h, BIN);
  Serial.print(",");
  Serial.println(l_l, BIN);
#endif

  digitalWrite(_SS, LOW);
  h_h = SPI.transfer(((*val) >> 24) & 0xFF);  // D31-D24
  h_l = SPI.transfer(((*val) >> 16) & 0xFF);  // D23-D16
  l_h = SPI.transfer(((*val) >> 8) & 0xFF);   // D15-D08
  l_l = SPI.transfer((*val) & 0xFF);          // D07-D00
  digitalWrite(_SS, HIGH);
  *val = (uint32_t)(((uint32_t)h_h << 24) | ((uint32_t)h_l << 16) | ((uint32_t)l_h << 8) | l_l);

#ifndef _PDEBUG

  Serial.println("Receiving SPI32bit");
  Serial.print("HEX: ");
  Serial.print(h_h, HEX);
  Serial.print(",");
  Serial.print(h_l, HEX);
  Serial.print(",");
  Serial.print(l_h, HEX);
  Serial.print(",");
  Serial.println(l_l, HEX);
  Serial.print("BIN: ");
  Serial.print(h_h, BIN);
  Serial.print(",");
  Serial.print(h_l, BIN);
  Serial.print(",");
  Serial.print(l_h, BIN);
  Serial.print(",");
  Serial.println(l_l, BIN);
#endif

  return;  // Always return zero. Even if the things are not successful
}

// Builds the CRC table. Returns not relevant. But fills the crc_tab
static void ad7280_crc8_build_table(uint8_t *crc_tab) {
  uint8_t bit, crc;
  int16_t cnt, i;

  for (cnt = 0; cnt < 256; cnt++) {
    crc = cnt;
    for (i = 0; i < 8; i++) {
      bit = crc & HIGHBIT;
      crc <<= 1;
      if (bit)
        crc ^= POLYNOM;
    }
    crc_tab[cnt] = crc;
  }
}

// Calculates the CRC for the transmission packets: Returns CRC(8bit)
static uint8_t ad7280_calc_crc8(uint8_t *crc_tab, uint32_t val) {
  uint8_t crc;

  crc = crc_tab[(uint16_t)(val >> 16 & 0xFF)];
  crc = crc_tab[crc ^ (val >> 8 & 0xFF)];

  return crc ^ (val & 0xFF);
}

// Check crc routine for the received packets. Returns 0 if correct else -1.
static int8_t ad7280_check_crc(struct ad7280_state *st, uint32_t val) {
  uint8_t crc = ad7280_calc_crc8(st->crc_tab, val >> 10);

  if (crc != ((val >> 2) & 0xFF))
    return -1;

  return 0;
}

// Delay
static void ad7280_delay(struct ad7280_state *st) {
  delay(st->readback_delay_ms);
}

// Send valid frame on SPI. Returns not relevant. but val will contain the received value.
static int8_t __ad7280_read32(struct spi_device *spi, uint32_t *val) {
  *val = AD7280A_READ_TXVAL;  //0xF800030A
  transferspi32(val);         // recieved value will be in <val>
  return 0;
}

// Send Data (val) to devices. Returns not relevant.
static int8_t ad7280_write(struct ad7280_state *st, uint32_t devaddr,
                           uint32_t addr, uint8_t all, uint32_t val) {
  uint32_t reg = (devaddr << 27 | addr << 21 | (val & 0xFF) << 13 | all << 12);

  reg |= ad7280_calc_crc8(st->crc_tab, reg >> 11) << 3 | 0x2;
  reg = (uint32_t)(reg);

  //return spi_write(st->spi, &reg, 4);  Wrtite to SPI.
  transferspi32(&reg);
  return 0;
}

// Read from a specific device register : Returns register value
static int8_t ad7280_read(struct ad7280_state *st, uint32_t devaddr,
                          uint32_t addr) {
  uint32_t tmp;

  /* turns off the read operation on all parts */
  ad7280_write(st, AD7280A_DEVADDR_MASTER, AD7280A_CONTROL_HB, 1,
               AD7280A_CTRL_HB_CONV_INPUT_6CELL | AD7280A_CTRL_HB_CONV_RES_READ_NO | st->ctrl_hb);


  /* turns on the read operation on the addressed part */
  ad7280_write(st, devaddr, AD7280A_CONTROL_HB, 0,
               AD7280A_CTRL_HB_CONV_INPUT_6CELL | AD7280A_CTRL_HB_CONV_RES_READ_6CELL | st->ctrl_hb);


  /* Set the address of the register on the device to be read from */
  ad7280_write(st, devaddr, AD7280A_READ, 0, addr << 2);

  /* Valid read so that the value can be received*/
  __ad7280_read32(st->spi, &tmp);

  if (ad7280_check_crc(st, tmp))  // Check the received CRC
    return -1;

  if (((tmp >> 27) != devaddr) || (((tmp >> 21) & 0x3F) != addr))
    return -1;  // Check if the received device and register address is correct.

  return (tmp >> 13) & 0xFF;
}

// Read from an Analog channel with start of Conversion as CS start. Returns the value of the ADC count received.
static uint16_t ad7280_read_channel(struct ad7280_state *st, uint32_t devaddr,
                                    uint32_t addr) {
  int8_t ret;
  uint32_t tmp, temp2;

  /* Write on Read Register of "the device" the Register address of channel*/
  ret = ad7280_write(st, devaddr, AD7280A_READ, 0, addr << 2);

  /* Write on Ctrl_HB of "all device" to convert all but not to read all.*/
  ret = ad7280_write(st, AD7280A_DEVADDR_MASTER, AD7280A_CONTROL_HB, 1,
                     AD7280A_CTRL_HB_CONV_INPUT_6CELL | AD7280A_CTRL_HB_CONV_RES_READ_NO | st->ctrl_hb);

  /* Write on Ctrl_HB of "the device" to convert all and to read all 
	and to start the conversion as CS start*/
  ret = ad7280_write(st, devaddr, AD7280A_CONTROL_HB, 0,
                     AD7280A_CTRL_HB_CONV_INPUT_6CELL | AD7280A_CTRL_HB_CONV_RES_READ_6CELL | AD7280A_CTRL_HB_CONV_START_CS | st->ctrl_hb);

  /*Delay*/
  ad7280_delay(st);

  /*Valid write to get the channel value*/
  __ad7280_read32(st->spi, &tmp);

  if (ad7280_check_crc(st, tmp))  // Check the received CRC
    return 0;

  if (((tmp >> 27) != devaddr) || (((tmp >> 23) & 0xF) != addr))
    return 1;  // Check if the received device and register address is correct.
  temp2 = (tmp >> 11) & 0xFFF;
  temp2 = temp2 + 935;
  if (temp2 < 936) {
    return 0;
  }
  return temp2;
}

// Read from all devices the channels of VIN and AUX at CS frame start. Returns the sum of all the voltages.
static uint32_t ad7280_read_all_channels(struct ad7280_state *st, uint32_t cnt,
                                         uint16_t *array) {
  uint8_t ret;
  uint32_t i;
  uint32_t tmp, sum = 0;
  /* Write to all the read registers of all the devices the address
	of first channel register i.e AD7280A_CELL_VOLTAGE_1*/
  ret = ad7280_write(st, AD7280A_DEVADDR_MASTER, AD7280A_READ, 1,
                     AD7280A_CELL_VOLTAGE_1 << 2);

  /*Write to all the Control HB of all the devices, 
	select all channels, read all, Start conversion at CS Start*/
  ret = ad7280_write(st, AD7280A_DEVADDR_MASTER, AD7280A_CONTROL_HB, 1,
                     AD7280A_CTRL_HB_CONV_INPUT_6CELL | AD7280A_CTRL_HB_CONV_RES_READ_6CELL | AD7280A_CTRL_HB_CONV_START_CS | st->ctrl_hb);

  ad7280_delay(st);

  for (i = 0; i < cnt; i++) {
    __ad7280_read32(st->spi, &tmp);

    if (ad7280_check_crc(st, tmp))
      return 0xFFF;

    array[i] = ((tmp >> 11) & 0xFFF);
    /* only sum cell voltages */
    if (((tmp >> 23) & 0xF) <= AD7280A_CELL_VOLTAGE_6) {
      sum += ((tmp >> 11) & 0xFFF);
      //Serial.println(sum,HEX); //
    }
  }

  return sum;
}

/* 4x 8bit to 32bit conversion */
void show32bit(uint32_t *val) {
  byte h_h;  // D31-D24 received
  byte h_l;  // D23-D16 received
  byte l_h;  // D15 -D8 received
  byte l_l;  // D07 -D0 received

  h_h = ((*val) >> 24) & 0xFF;
  h_l = ((*val) >> 16) & 0xFF;
  l_h = ((*val) >> 8) & 0xFF;
  l_l = (*val) & 0xFF;
  Serial.print("HEX: ");
  Serial.print(h_h, HEX);
  Serial.print(",");
  Serial.print(h_l, HEX);
  Serial.print(",");
  Serial.print(l_h, HEX);
  Serial.print(",");
  Serial.println(l_l, HEX);
  Serial.print("BIN: ");
  Serial.print(h_h, BIN);
  Serial.print(",");
  Serial.print(h_l, BIN);
  Serial.print(",");
  Serial.print(l_h, BIN);
  Serial.print(",");
  Serial.println(l_l, BIN);
  return;
}
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
void loop() {
    unsigned long currentMillis = millis();
  // try to reconnect if WiFi is disconnected
  if ((WiFi.status() != WL_CONNECTED) && (currentMillis - previousMillis >=interval)) {
    Serial.print(millis());
    Serial.println("Reconnecting to WiFi...");
    WiFi.disconnect();
    WiFi.reconnect();
    previousMillis = currentMillis;
  }
  init_ad7280()
  /* Read cell voltages from AD7280, map it to corresponding variable and calculate charge status */
  int batteryVoltages[4];
  batteryVoltages[0] = ad7280_read_channel(&ADinst, AD7280A_DEVADDR_MASTER, AD7280A_CELL_VOLTAGE_1);
  batteryVoltages[1] = ad7280_read_channel(&ADinst, AD7280A_DEVADDR_MASTER, AD7280A_CELL_VOLTAGE_2);
  batteryVoltages[1] = ad7280_read_channel(&ADinst, AD7280A_DEVADDR_MASTER, AD7280A_CELL_VOLTAGE_2);
  batteryVoltages[2] = ad7280_read_channel(&ADinst, AD7280A_DEVADDR_MASTER, AD7280A_CELL_VOLTAGE_3);
  batteryVoltages[3] = ad7280_read_channel(&ADinst, AD7280A_DEVADDR_MASTER, AD7280A_CELL_VOLTAGE_6);
  int batteryPercentages[] = { map(batteryVoltages[0], 3200, 4200, 0, 100), map(batteryVoltages[1], 3200, 4200, 0, 100), map(batteryVoltages[2], 3200, 4200, 0, 100), map(batteryVoltages[3], 3200, 4200, 0, 100) };
/*ignore any values with CRC error */
  if(batteryPercentages[0] < 0 || batteryPercentages[1] < 0 || batteryPercentages[2] < 0 || batteryPercentages[3] < 0)
  {
	  return;
  }
  if(millis() - lastMillis > 500)
  {
    for(int i = 0; i < 4; i++)
    {
      if(batteryPercentages[i] < 100)
      {
        digitalWrite(LEDPins[i], !digitalRead(LEDPins[i]));
      }
      else if(batteryPercentages[i] = 100)
      {
        digitalWrite(LEDPins[i], HIGH);
      }
      else if(batteryPercentages[i] <= 0)
      {
        digitalWrite(LEDPins[i], LOW);
      }
    }
  }
  int totalVoltage = batteryVoltages[0] + batteryVoltages[1] + batteryVoltages[2] + batteryVoltages[3];
  int totalPercentage = (batteryPercentages[0] + batteryPercentages[1] + batteryPercentages[2] + batteryPercentages[3]) / 4;
  if (totalPercentage < 0) {
    totalPercentage = 0;
  }
  Serial.print("Voltages: ");
  Serial.print(batteryVoltages[0]);
  Serial.print(", ");
  Serial.print(batteryVoltages[1]);
  Serial.print(", ");
  Serial.print(batteryVoltages[2]);
  Serial.print(", ");
  Serial.println(batteryVoltages[3]);

  Serial.print("Percentages: ");
  Serial.print(batteryPercentages[0]);
  Serial.print(", ");
  Serial.print(batteryPercentages[1]);
  Serial.print(", ");
  Serial.print(batteryPercentages[2]);
  Serial.print(", ");
  Serial.println(batteryPercentages[3]);
  
  /* send voltage levels and charge level to webpage */
  String jsonData = "{\"voltages\": [" + String(batteryVoltages[0]) + "," + String(batteryVoltages[1]) + "," + String(batteryVoltages[2]) + "," + String(batteryVoltages[3]) + "], \"percentages\": [" + String(batteryPercentages[0]) + "," + String(batteryPercentages[1]) + "," + String(batteryPercentages[2]) + "," + String(batteryPercentages[3]) + "], \"totalVoltage\": " + String(totalVoltage) + ", \"totalPercentage\": " + String(totalPercentage) + "}";
  ws.textAll(jsonData);

  delay(1000);
}

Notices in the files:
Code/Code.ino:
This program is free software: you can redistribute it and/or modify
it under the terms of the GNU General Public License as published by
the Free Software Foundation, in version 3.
